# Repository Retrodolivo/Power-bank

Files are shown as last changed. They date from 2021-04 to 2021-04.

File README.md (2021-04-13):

# Power-bank
## Description

<p align="center">
</p>

**Telling you right away - this is an educational project. My goal was to build a needlessly complex system to try a new ICs, sensors, etc.**
Power bank is a portable charger device. It designed to recharge electronic gadgets when you don't have access to a regular wall charger. As I don't dont have one I decide to build my own power bank. 

### Features 
* 3 parallel 18650 Li-Po batteries with total capacity up to 10000mAh(at 3.7V);
* One output USB connector. USB type-c input connector;
* Output parameters: 5V 2A;
* OLED display. Real-time indication of charging statuses;
* 4 level LED battery capacity indication;
* Beautiful LED glowing :)

### Power

<p align="center">
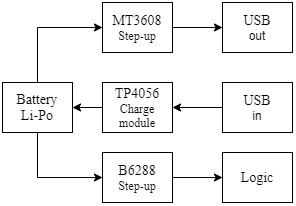
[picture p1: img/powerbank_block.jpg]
</p>

Step-up MT3608 based module is responsible for power bank output characteristics MT3608 is generating 5V output. 18650 minimal allowed voltage is 2.5V. MT3608 minimum input voltage is 2V. So requared 5V would be during full battery lifespan. TP4056 is an linear charger IC. It work is to control charge cycle, to charge to fix 4.2V with constant current which can be programmed externally with a single resistor. To power up a device logic part a step-up B6288 based module was used. It is 5V 0.4W module(max current was determinated experimentally).

### Logic

<p align="center">
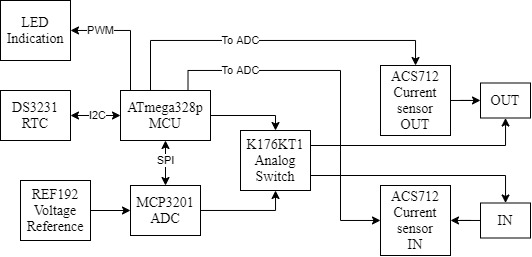
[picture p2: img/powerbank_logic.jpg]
</p>

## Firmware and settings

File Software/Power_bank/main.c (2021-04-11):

#include "main.h"

static void print_time(uint8_t x, uint8_t y);
static void print_Wh(uint8_t x, uint8_t y);
static void print_current(uint8_t x, uint8_t y);
static void print_voltage(uint8_t x, uint8_t y);
static void ports_init(void);
static void enable_wh_time_calc(void);
static void welcome_message(void);

enum Oled_show_mode oled_show_mode = MODEIDLE;

enum i2c_speed speed = Fast;
Time_t t = {0};
	
static char buff[100];			//display buffer
static float total_Wh = 0;
static uint8_t cnt, temp;

static void init_routine(void)
{
	button_init();
	pwm_led_init();
	ports_init();
	spi_init();
	i2c_init(speed);
	rtc_init();
	oled_init();
	adc_init();
	adc_start();
	sei();
}
static void ports_init(void)
{
	/*K176KT1 is analog switch IC. Is used for switching adc mcp3201 input.*/	
	ANLG_SWITCH_DDR  |= 1<<SWITCH_INPUT_PIN | 1<<SWITCH_OUTPUT_PIN;
	ANLG_SWITCH_PORT &= ~(1<<SWITCH_INPUT_PIN | 1<<SWITCH_OUTPUT_PIN);
	/*Is used to know if power bank is charging*/
	INPUT_SENS_DDR  &= ~(1<<INPUT_SENS_PIN);
	INPUT_SENS_PORT &= ~(1<<INPUT_SENS_PIN);							
}

static void welcome_message(void)
{
	sprintf(buff, "Power bank");
	oled_print(31, 3, buff);
	sprintf(buff, "10000mAh");
	oled_print(38, 4, buff);
}

int main(void)
{
	init_routine();
	
	while(1)
	{
		_delay_ms(300);
		if(oled_show_mode == MODEIDLE)
		{
			welcome_message();
			if(CHARGING)
			{
				sprintf(buff,"IN");
				oled_print(10, 7, buff);
				if(temp == 0)
				{
					rtc_set_time(&t, 0, 0);
					total_Wh = 0;
					
					SWITCH_INPUT_PIN_HIGH;
					SWITCH_OUTPUT_PIN_LOW;
					enable_wh_time_calc();
					
					temp = 1;
				}
			}
			if(NOT_CHARGING && (get_current() > 0.15))
			{
				sprintf(buff,"OUT");
				oled_print(90, 7, buff);
				if(temp == 0)
				{
					rtc_set_time(&t, 0, 0);
					total_Wh = 0;
					
					SWITCH_OUTPUT_PIN_LOW;
					SWITCH_INPUT_PIN_HIGH;
					enable_wh_time_calc();
					
					temp = 1;
				}
			}
		}
	}
}

/*
	Interrupt upon button press
*/
ISR(INT0_vect)
{
	if(oled_show_mode == MODEIDLE)
	{
		if(CHARGING)
		{
			oled_clear();
			sprintf(buff, "IN");
			oled_print(95, 0, buff);
			oled_show_mode = MODEINPUT;
			SWITCH_INPUT_PIN_HIGH;
			SWITCH_OUTPUT_PIN_LOW;
			enable_wh_time_calc();			
		}
		
		if(NOT_CHARGING && (get_current() > 0.15))
		{
			oled_clear();
			sprintf(buff, "OUT");
			oled_print(95, 0, buff);
			oled_show_mode = MODEOUTPUT;
			SWITCH_INPUT_PIN_LOW;
			SWITCH_OUTPUT_PIN_HIGH;
			enable_wh_time_calc();			
		}			
	} 		
}

static void print_time(uint8_t x, uint8_t y)
{
	oled_goto(x, y);
	if(oled_show_mode == MODEINPUT || oled_show_mode == MODEOUTPUT)
	{	
		rtc_set_time(&t, 0, 0);
		sprintf(buff,"t = %02d:%02d:%02d", t.hour, t.min, t.sec);
		oled_print6x8(buff);
	}
}

static void print_Wh(uint8_t x, uint8_t y)
{
	oled_goto(x, y);
	
	float power;
	
	power = get_voltage() * get_current();
	/*get absolute value of 'power'*/
	if(power < 0)
		power *= -1;
	total_Wh += power / 3600;
	if(oled_show_mode == MODEINPUT || oled_show_mode == MODEOUTPUT)
	{
		sprintf(buff,"E = %.3fWh", total_Wh);
		oled_print6x8(buff);
	}
}

static void print_voltage(uint8_t x, uint8_t y)
{
	oled_goto(x, y);
	if(oled_show_mode == MODEINPUT || oled_show_mode == MODEOUTPUT)
	{
		sprintf(buff,"U = %.2fV", get_voltage());
		oled_print6x8(buff);
	}
}

static void print_current(uint8_t x, uint8_t y)
{
	oled_goto(x, y);
	if(oled_show_mode == MODEINPUT || oled_show_mode == MODEOUTPUT)
	{
		sprintf(buff,"I = %.2fA", get_current());
		oled_print6x8(buff);
	}
}

static void enable_wh_time_calc(void)
{
	/*------------set Wh and time fps--------------*/
	/*Prescaler - 1024*/
	TCCR0B = 1<<CS00 | 1<<CS02;	
	/*Enable interrupt upon overflow*/
	TIMSK0 |= 1<<TOIE0;							
	/*Interrupt upon falling edge*/
	EICRA |= 1<<ISC11;
	/*Enable external interrupt INT1*/
	EIMSK |= 1<<INT1;	
}

/*------------Set fps of I and V indication-----------*/
ISR(TIMER0_OVF_vect)
{
	if(cnt == 5)
	{
		print_voltage(0, 0);
		print_current(0, 2);
		cnt = 0;
	}
	cnt++;
}

/*
	Interrupt at 1Hz wave of RTC
	print Wh and time every sec	
*/
ISR(INT1_vect)
{
	print_Wh(0, 4);
	print_time(0, 6);			
}

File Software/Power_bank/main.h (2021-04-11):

#ifndef MAIN_H_
#define MAIN_H_

#define F_CPU 16000000UL

#include <avr/io.h>
#include <avr/interrupt.h>
#include <util/delay.h>
#include <stdio.h>
#include <stdlib.h>

#include "i2c.h"
#include "spi.h"
#include "oled_ssd1306.h"
#include "oled_font.h"
#include "adc3201.h"
#include "acs712.h"
#include "rtc_ds3231.h"
#include "pwm_led.h"
#include "button.h"


#define ANLG_SWITCH_DDR				DDRD
#define ANLG_SWITCH_PORT			PORTD
 
#define SWITCH_INPUT_PIN			PORTD6
#define SWITCH_OUTPUT_PIN			PORTD7

#define SWITCH_INPUT_PIN_LOW		ANLG_SWITCH_PORT &= ~(1<<SWITCH_INPUT_PIN);
#define SWITCH_OUTPUT_PIN_LOW		ANLG_SWITCH_PORT &= ~(1<<SWITCH_OUTPUT_PIN);
#define SWITCH_INPUT_PIN_HIGH		ANLG_SWITCH_PORT |= 1<<SWITCH_INPUT_PIN;
#define SWITCH_OUTPUT_PIN_HIGH		ANLG_SWITCH_PORT |= 1<<SWITCH_OUTPUT_PIN;

#define INPUT_SENS_DDR				DDRD
#define INPUT_SENS_PORT				PORTD
#define INPUT_SENS_PIN				PORTD5

#define	CHARGING					(PIND&(1<<INPUT_SENS_PIN))
#define	NOT_CHARGING				(!(PIND&(1<<INPUT_SENS_PIN)))

enum Oled_show_mode
{
	MODEIDLE,
	MODEINPUT,
	MODEOUTPUT
};


#endif /* MAIN_H_ */

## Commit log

2021-04-10 add Power-bank project
    [CONV_R0.25S-0505_E.PcbLib, CONV_RAZ-2405S.PcbLib, DC+DC.PcbLib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]
2021-04-10 refactor "i2c"
2021-04-11 add "button"
2021-04-11 add "pwm_led"
2021-04-11 rename some nets
    [SchemeP1.SchDoc]
2021-04-11 update "spi"
